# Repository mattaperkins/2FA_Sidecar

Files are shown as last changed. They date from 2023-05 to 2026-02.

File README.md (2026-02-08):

<PRE>
// 2FA Sidecar
// Matt Perkins - Copyright (C) 2025
// Spawned out of the need to often type a lot of two factor authentication
// but still have some security while remaining mostly isolated from the host system.
// See github for 3D models and wiring diagram.
/*

    This program is free software: you can redistribute it and/or modify
    it under the terms of the GNU General Public License as published by
    the Free Software Foundation, either version 3 of the License, or
    (at your option) any later version.

    This program is distributed in the hope that it will be useful,
    but WITHOUT ANY WARRANTY; without even the implied warranty of
    MERCHANTABILITY or FITNESS FOR A PARTICULAR PURPOSE.  See the
    GNU General Public License for more details.

    You should have received a copy of the GNU General Public License
    along with this program.  If not, see <https://www.gnu.org/licenses/>.

*/

</PRE>
<h2>About</h2> 
<p>The 2FA Sidecar is a small external keyboard-like device with five or two keys specifically designed for generating and sending time-based two-factor authentication (2FA) codes with a single key press. It is primarily designed to be compatible with Google's 2FA implementation known as Time-Based One-Time Password (TOTP), which is specified in RFC 6238.
</p><p>
The purpose of the 2FA Sidecar is to simplify the process of using 2FA codes when switching between different security levels in various parts of a network. Instead of having to manually open your phone, retrieve the code, and type it in, the sidecar device allows you to generate and send the code with just a single key press.
</p><p>

The device supports up to five different TOTP codes for different systems, allowing you to manage multiple 2FA-enabled accounts or services. Additionally, it features a TFT screen on the front where you can read the generated code if you prefer to type it manually.
</p><p>

The 2FA Sidecar is compatible with any platform that supports USB HID (Human Interface Device) protocols, making it versatile and usable across a wide range of devices and operating systems.

</p>
<h2>Versions</h2>
<pre>
1.0 Start of project. 
1.3 First Public Release.
1.5 Good working copy with basic cleanup.
1.10 Includes new PIN for access after bootup.
1.11 Added the mini 2 key version with slight change to the code to select at compile time. 
1.13 Make some changes to clean thing up and allow manual entry of time via serial in the future
1.21 Add support for setting the esp32 clock via USB and the host computer clock 
</pre>

<p>
The system is made up of a 5 Key or 3 Key sidecar 3d model that will house an Adafruit Feather S3 Reverse module and 5 Cherry MX type keys It's a fairly simple project to print and build and you should be able to finish it off in a few hours. (including the printing) 
<p>

<a href = "https://www.youtube.com/embed/u4l2TvUD5HY"> 
A short youtube video is also available here. 
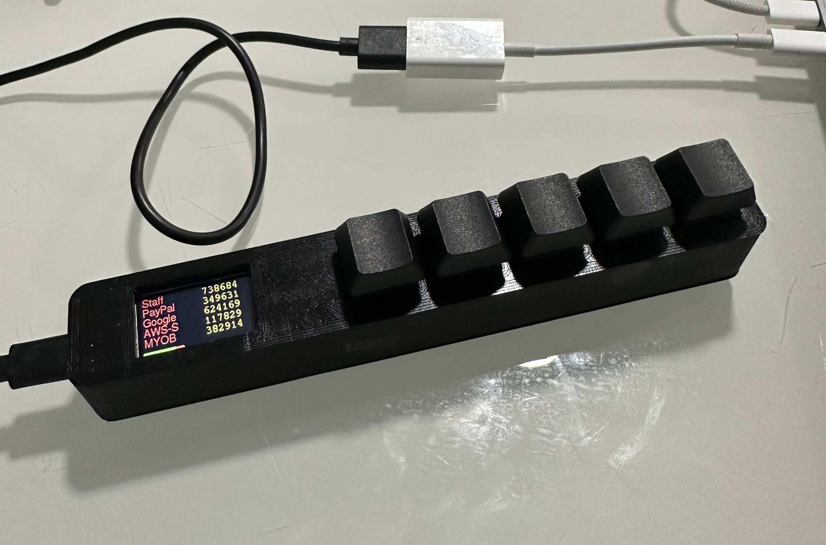
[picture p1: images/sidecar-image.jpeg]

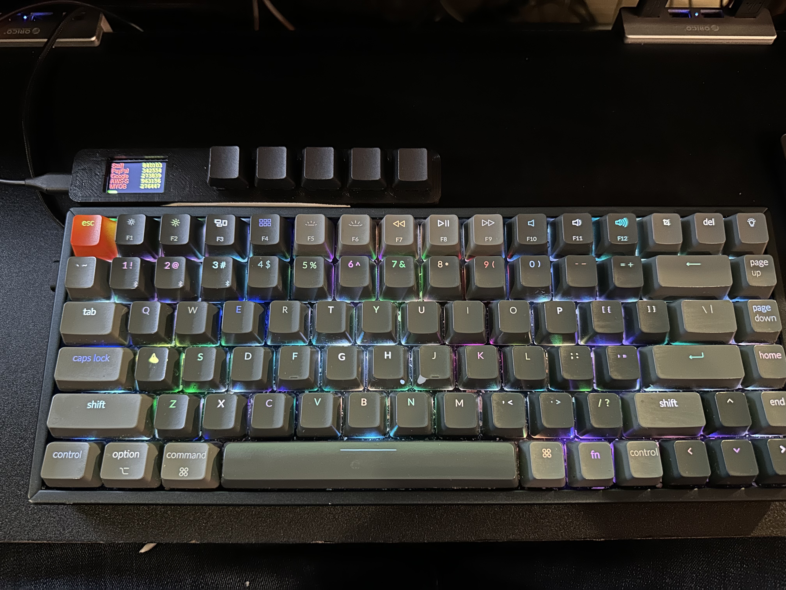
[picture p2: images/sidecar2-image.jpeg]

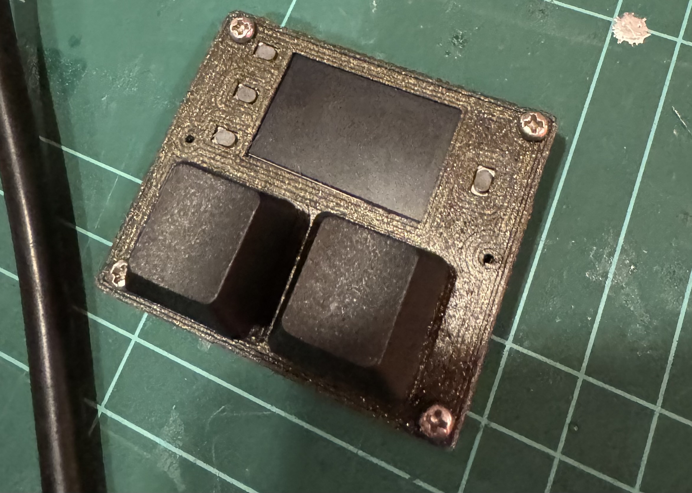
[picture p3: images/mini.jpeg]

</a>
</p>

<h2>Security</h2>

When the sidecar is running in normal mode it is not accessible by any network services and maintains a network connection to update accurate time from a time server only. So it should not be easy for a malicious actor to connect to the sidecar and access the TOTP salt. It would be however possible to download new code to the ESP32 and then retrieve the salts from the parameters memory. So if you want to keep it as secure as possible. You may burn the protective Efuses on the ESP32 to protect flash memory. Even with this done it may be possible to retrieve the salts by much smarter people then i. So i warrant nothing. Use it at your own risk. It goes without question to say also that if someone is in possession of the device they can use your TOTP so you need to keep the device secure. In the same way you would with any key fob. 

<h2>Hardware Required</h2>
<p>Adafruit ESP32-S3 Reverse TFT Feather - 4MB Flash, 2MB PSRAM, STEMMA QT https://www.adafruit.com/product/5691 </p>
<p>Case can be printed from PLA/ABS or whatever really</p>
<p>5 X Cherry MX switches https://core-electronics.com.au/cherry-mx-switch.html click=good</p>
<p>5 X Cherry MX key caps you can source your own or print them many people sell them There's all sorts.</p>
<p>Hookup wire soldering iron and hand tools, super glue </p> <p>- Core electronics stock all of the above</p> 

<h2>Dependences</h2>
<pre>
TOTP-RFC6238-generator - By dirkx - which saved me a lot of work. 
Adafruit_GFX_Library at version 1.11.5 
Adafruit_BusIO at version 1.14.1 
Wire at version 2.0.0
SPI at version 2.0.0
Adafruit_ST7735_and_ST7789_Library at version 1.10.0
Preferences at version 2.0.0
MultiButton at version 1.2.0
USB at version 2.0.0 
WiFi at version 2.0.0
AsyncTCP at version 3.4.10
ESPAsyncWebSrv at version 1.2.9
FS at version 2.0.0
TOTP-RC6236-generator at version 1.0.0
Base32-Decode at version 1.0.1
ESPmDNS at version 2.0.0
ArduinoOTA at version 2.0.0
</pre>

<h2>3D Printing</h2>
The 3d model is based on cherry mx macro pad by LeoAnth found on thingiverse. I remixed that design to fit the Reverse TFT Feather it also has a pin hole so you can access the reset button externally so once complete the boot loader can be accessed.  It prints fine without supports on my snap maker in both ABS and PLA. Print it upside down with no special options. The Lid can then be glued in place once the project is complete and tested. There are also two small plastic squares that can be used to hold the feather in position. Use a drop of glue to hold them in position. I then just used 6 drops of super glue to afix the bottom. 
</p>
<pre>
base.stl - Bottom plate. 
main_body.stl - Main unit print upside down keys pop in. 
shroud.stl - Optional but to put around keys. 
standoffs.stl - Plastic bits to hold the ESP32 in place 
mini.stl - Mini two key version complete. 
</pre>

<h2>Hookup </h3>
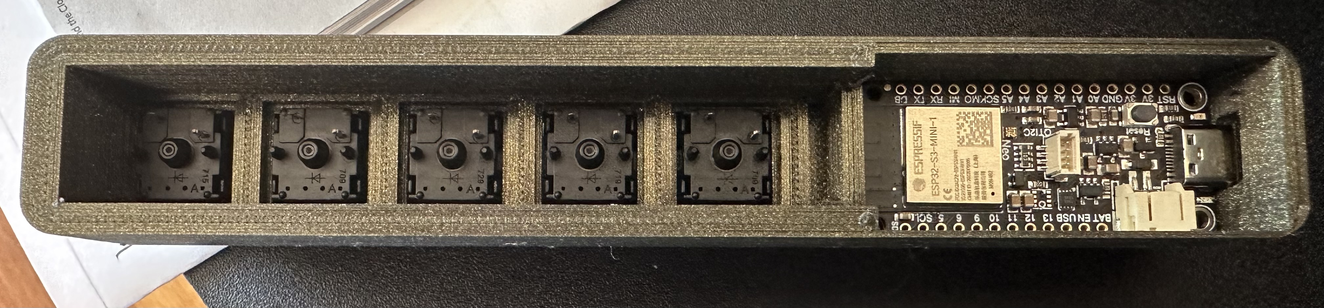
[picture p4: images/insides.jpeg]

To Wire the Cherry MX keys is very simple. Wire one leg of each key to ground and then run a wire from the other leg of each key to the following pins. You might want to solder the switches before you pop them into the case. They can be held with a drop of glue but will fit snugly without as well.
<pre>
Key 1 = Pin (5)
Key 2 = Pin (6)
Key 3 = Pin (9)
Key 4 = Pin (10)
Ket 5 = Pin (11)
</pre>

The two key version you will only need to wire two pins. I found it easer to get the ground from the case of the esp32 RF can. Use some cutters to trim out some space for the wire but not to much as the display is not held firmly in place. 

That's it. Once you flash the esp32 and power up press key 1 within the first 3 second of booting and you will enter a self test and config mode. In the self test mode you can push each key one by one and it will verify your soldering and operation of the keys. Once all 5 keys have been pushed the system will proceed to the config web menu.
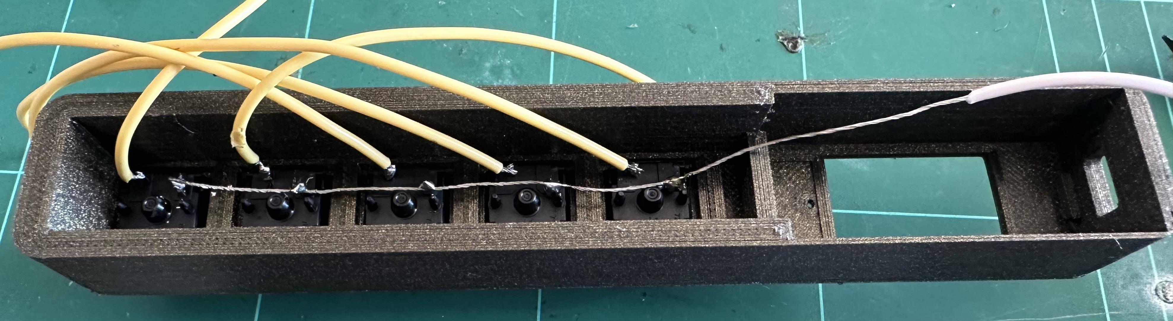
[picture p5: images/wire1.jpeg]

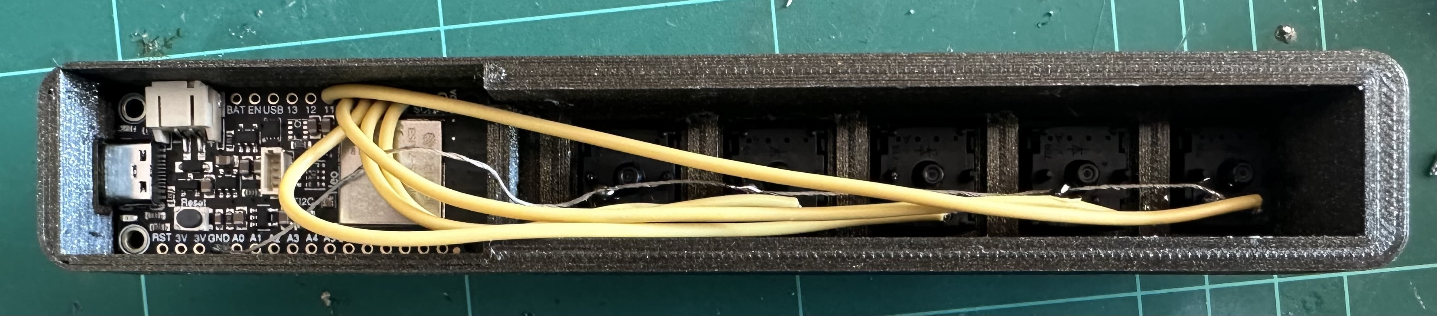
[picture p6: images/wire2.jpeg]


<h2>How to configure</h2>

Configuration is very simple. On powering up the sidecar press key 1 (the key closest to the TFT) within 3 seconds. As it's printing all the dots ... <p> You will then enter the self test menu. Press each key in turn until you see "test pass" If you do not see a test passed check your wiring. Once the test is passed the system will enter a mode where you edit the config</p><p>

At this point you will need to add some TOTP salts. These can be found when your one time password is initially generated on the service you want to authenticate . It will usually represent as a QR code. When you see the QR code there is usually an option display your code manually. Find that option which will typically display a group of base32 letters. It might look something like this WWKAAJJWJJAASZ====. </p><p>  

The sidecar can store up to five TOTP salts (one for each key) so make sure you have them all in advance ready to configure your sidecar. Once your ready and the self test has passed you will be able to connect to the sidecar over wifi. Use your smart phone or computer to scan for the SSID  "Key-Sidecar" and connect. Once connected open your favorite browser and connect to http://192.168.4.1 and you should see the config menu 
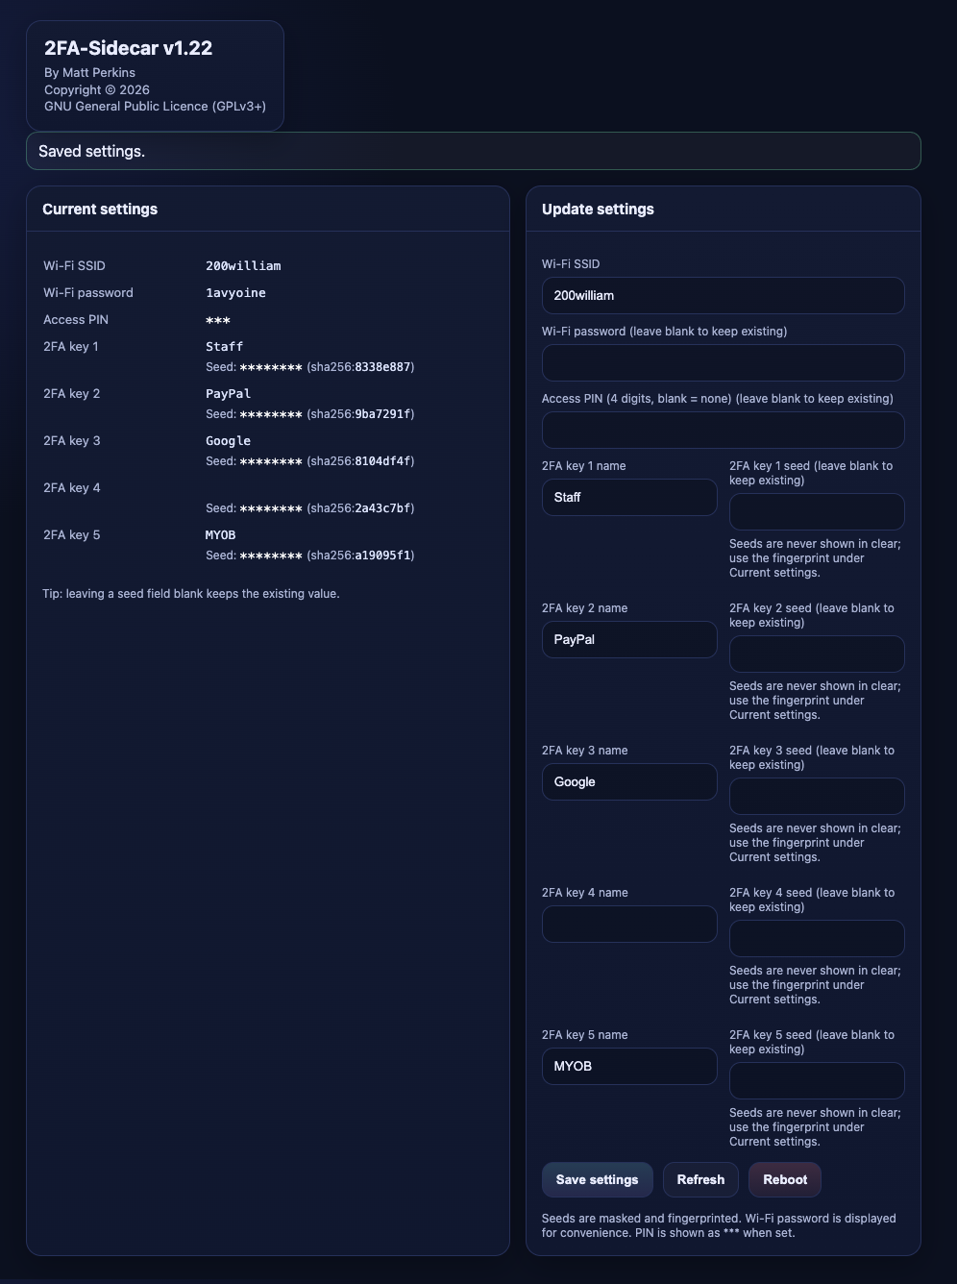
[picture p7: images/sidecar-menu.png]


</p><p> 

You may then configure your system SSID and password so the sidecar can get an accurate time at startup as well as your 5 TOTP's and a corresponding name for each.  
</p><p> 
A note about stored values.  The system does not display a value you have stored after you submit. This is on propose to protect the values stored in those options. If the values were displayed it would be trivial for a bad actor to grab the TOTP salts out of the config menu. </p><p>
<P>
As of version 1.20, there is now an option to set the ESP32 clock via USB for situations where Wi-Fi is not available (such as when you're on the road). If Wi-Fi cannot be found, the TFTP display will show: "WiFi not found. USB fallback." While this message is displayed, use the companion Python program settime.py to set the clock over USB. You will need to edit the Python script to include the correct path to your serial device connected to the sidecar.
</p>

Once everything is configured you can reboot your sidecar and it will boot up in display mode and connect to your local wifi. Grab the time and start spitting out 5 TOTP's every 30 seconds. The unit will also then show up on your computer as a standard USB type keyboard.  When you need to provide a 2FA for authentication on a web site or in a ssh simply tap the key that corresponds to one of the 5 TOTP's you want and the sidecar will type the TOTP for you and press enter. 
</p><p> 
That's it your done. Your 15 second process is now less then 500ms.  Your welcome. 
</p>

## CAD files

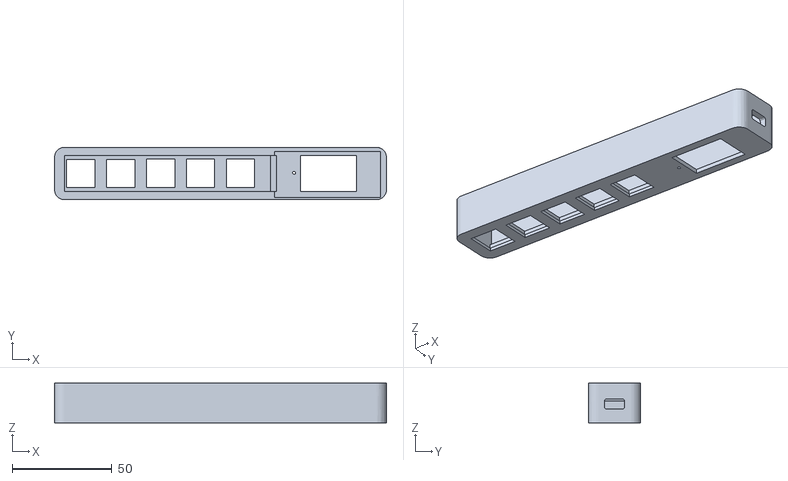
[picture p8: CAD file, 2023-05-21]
3d_model/main_body.stl
166.2 x 26.2 x 20.0

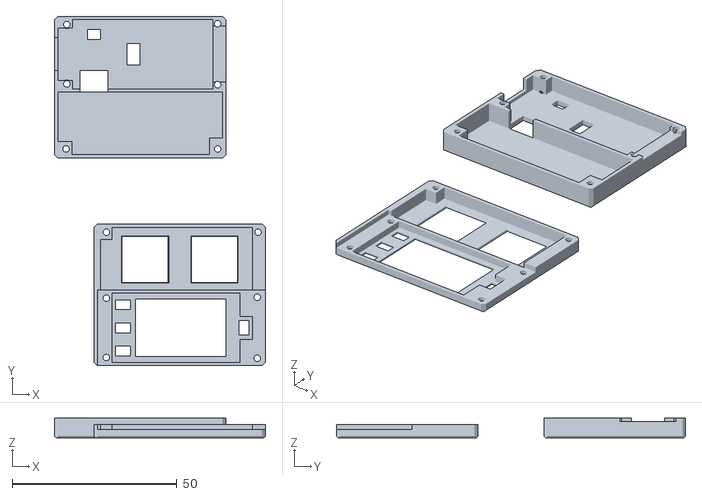
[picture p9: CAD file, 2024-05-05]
3d_model/mini.stl
64.0 x 106.0 x 6.00

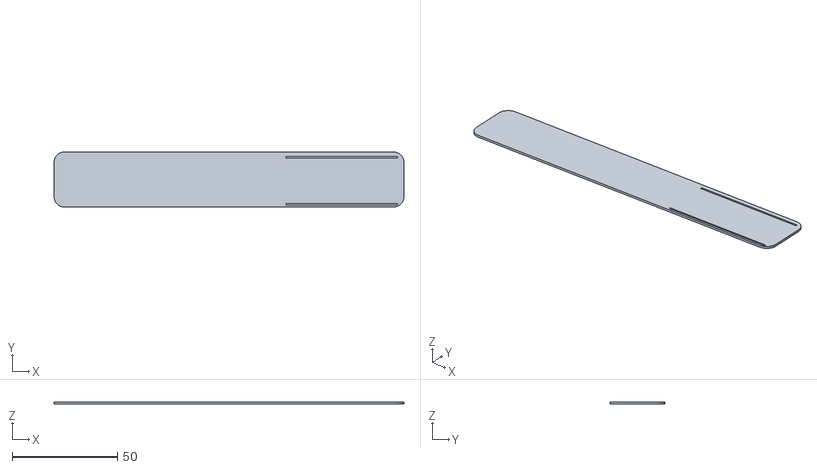
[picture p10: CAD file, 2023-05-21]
3d_model/base.stl
166.2 x 26.2 x 0.998

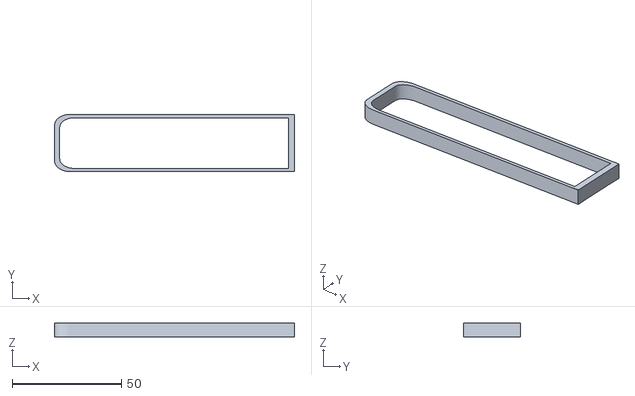
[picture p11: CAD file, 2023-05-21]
3d_model/shround.stl
110.0 x 26.2 x 6.56

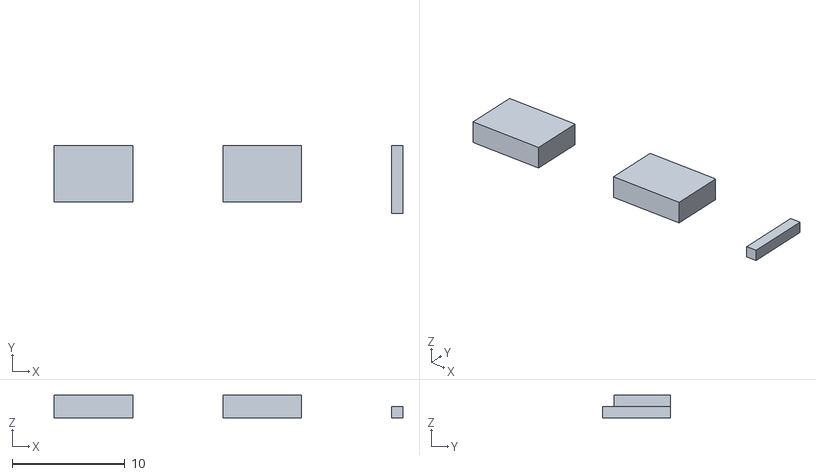
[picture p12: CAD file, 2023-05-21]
3d_model/standoffs.stl
31.0 x 6.00 x 2.00

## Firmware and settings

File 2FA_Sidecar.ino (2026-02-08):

// 2FA Sidecar
// Matt Perkins - Copyright (C) 2025
// Spawned out of the need to often type a lot of two factor authentication
// but still have some security while remaning mostly isolated from the host system.
// See github for 3D models and wiring diagram.
/*

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
*/

// Change for your country.
#define NTP_SERVER "au.pool.ntp.org" //Adjust to your local time perhaps. 
#define TZ "AEST" // Australian Estern time may be needed for clock display in the future. 



// Only other thing to select bellow is if your making the 5 key or 2 key version
// Default is 5 key.


char *mainver = "1.30";

#include <Adafruit_GFX.h>    // Core graphics library
#include <Adafruit_ST7789.h> // Hardware-specific library for ST7789
#include <SPI.h>
#include <Preferences.h> // perstant storage
#include <esp_system.h> 

// Misc Fonts
#include "Fonts/FreeSans9pt7b.h"
#include "Fonts/FreeSans12pt7b.h"
#include "Fonts/FreeSans18pt7b.h"
#include "Fonts/FreeMono12pt7b.h"

#include <string>



#include <PinButton.h> // Button Library 

#include <USB.h>
#include <USBHIDKeyboard.h>

#include <Arduino.h>
#ifdef ESP32
#include <WiFi.h>
#include <AsyncTCP.h>
#elif defined(ESP8266)
#include <ESP8266WiFi.h>
#include <ESPAsyncTCP.h>
#endif
#include <ESPAsyncWebSrv.h>


#include <lwip/apps/sntp.h>
#include <TOTP-RC6236-generator.hpp>
#include <ESPmDNS.h>
#include <ArduinoOTA.h>



// Init HID so we look like a keyboard
USBHIDKeyboard Keyboard;

// Init our 5 keys
int bargraph_pos;
int updateotp;
long time_x;
String inputBuffer = "";
int notime;

PinButton key1(5);
PinButton key2(6);
PinButton key3(9);
PinButton key4(10);
PinButton key5(11);


int keytest = 0;

// Select either the 5 key or 2 key version
// maxkeys = 15 for 5 key
// maxkeys = 3 for 2 key

int maxkeys = 3;
int sline = 0;
int pinno = 0;
int wifitry = 10; // Number of times to try wifi before falling back to serial.
String  in_pin;

// Incorrect Pin Delay
int pindelay = 3000;

AsyncWebServer server(80);

// Setup SSID
String ssid     = "Key-Sidecar";
String password;
String  pin;

String tfa_name_1;
String tfa_seed_1;

String tfa_name_2;
String tfa_seed_2;

String tfa_name_3;
String tfa_seed_3;

String tfa_name_4;
String tfa_seed_4;

String tfa_name_5;
String tfa_seed_5;

// Paramaters wifi
const char* PARAM_INPUT_1 = "ssid";
const char* PARAM_INPUT_2 = "password";
const char* PARAM_INPUT_3 = "pin";

// Paramaters 2FA
const char* TFA_INPUT_1 = "tfa_name_1";
const char* TFA_INPUT_2 = "tfa_seed_1";

const char* TFA_INPUT_3 = "tfa_name_2";
const char* TFA_INPUT_4 = "tfa_seed_2";

const char* TFA_INPUT_5 = "tfa_name_3";
const char* TFA_INPUT_6 = "tfa_seed_3";

const char* TFA_INPUT_7 = "tfa_name_4";
const char* TFA_INPUT_8 = "tfa_seed_4";

const char* TFA_INPUT_9 = "tfa_name_5";
const char* TFA_INPUT_10 = "tfa_seed_5";




// Init Screen
Adafruit_ST7789 tft = Adafruit_ST7789(TFT_CS, TFT_DC, TFT_RST);

// Init Preferences
Preferences preferences;


void setup() {

  
  // turn on backlite
  pinMode(TFT_BACKLITE, OUTPUT);
  digitalWrite(TFT_BACKLITE, HIGH);

  // turn on the TFT / I2C power supply
  pinMode(TFT_I2C_POWER, OUTPUT);
  digitalWrite(TFT_I2C_POWER, HIGH);
  delay(10);

  // initialize TFT
  tft.init(135, 240); // Init ST7789 240x135
  tft.setRotation(3);
  tft.fillScreen(ST77XX_BLACK);
  tft.setFont(&FreeSans9pt7b);

  // Print Bootup
  tft.setCursor(0, 0);
  tft.setTextColor(ST77XX_WHITE);
  tft.setTextWrap(true);
  tft.printf("\n2FA-Sidecar Ver %s\nBy Matt Perkins (C) 2024\n", mainver);
  tft.printf("Reset reason: %d\n", esp_reset_reason());
  tft.printf("Press K1 to enter config/test\n");

  // Check for key and go to setup /test mode
  int lcount = 0 ;
  while (lcount < 140) {

    key1.update();

    if (key1.isClick()) {
      setup_test();
      ESP.restart();
    }

    tft.printf(".");
    delay(10);
    lcount++;
  }

  tft.setFont(&FreeSans9pt7b);
  tft.fillScreen(ST77XX_BLACK);
  tft.setTextColor(ST77XX_WHITE);
  tft.setCursor(1, 15);
  tft.printf("2FA-Sidecar V%s - startup\n", mainver);

  preferences.begin("2FA_Sidecar", false);

  ssid = preferences.getString("ssid", "");
  password = preferences.getString("password", "");


  // load all pramaters
  tfa_name_1 = preferences.getString("tfa_name_1", "");
  tfa_seed_1 = preferences.getString("tfa_seed_1", "");

  tfa_name_2 = preferences.getString("tfa_name_2", "");
  tfa_seed_2 = preferences.getString("tfa_seed_2", "");

  tfa_name_3 = preferences.getString("tfa_name_3", "");
  tfa_seed_3 = preferences.getString("tfa_seed_3", "");

  tfa_name_4 = preferences.getString("tfa_name_4", "");
  tfa_seed_4 = preferences.getString("tfa_seed_4", "");

  tfa_name_5 = preferences.getString("tfa_name_5", "");
  tfa_seed_5 = preferences.getString("tfa_seed_5", "");

  WiFi.begin(ssid, password);

  sline = 0;
  while (WiFi.status() != WL_CONNECTED) {
    delay(1000);
    tft.printf("Establishing WiFi %d\n", wifitry);
    sline = sline + 1;
    wifitry = wifitry - 1;
    if (sline > 4) {
      tft.fillScreen(ST77XX_BLACK);
      tft.setTextColor(ST77XX_WHITE);
      tft.setCursor(1, 15);
      sline = 0 ;
    }
    if (wifitry == 0) {
      break;
    }
  }

  // If Wifi is found get time that way else try the serial port.
  if (wifitry != 0) {
    tft.fillScreen(ST77XX_BLACK);
    tft.setTextColor(ST77XX_WHITE);
    tft.setCursor(1, 15);
    tft.print("IP: ");
    tft.println(WiFi.localIP());
    tft.print("Wifi: ");
    tft.print(WiFi.RSSI());
    // start the NTP client
    configTzTime(TZ, NTP_SERVER);
    tft.println();
    tft.printf("NTP started:%s", TZ);
    time_t t = time(NULL);
    tft.printf(":%d", t);
    tft.println();
    delay(1000);
  } else {
    // Wifi Not found get time via serial/usb
    notime = 0;
    tft.fillScreen(ST77XX_BLACK);
    tft.setTextColor(ST77XX_WHITE);
    tft.setCursor(1, 15);
    tft.print("WiFi not found. USB fallback");

    Serial.begin(115200);
    Serial.println("Enter a Unix timestamp:");
    while (notime == 0) {
      while (Serial.available()) {
        char c = Serial.read();

        if (c == '\n' || c == '\r') {
          if (inputBuffer.length() > 0) {
            time_t unixTime = inputBuffer.toInt();

            struct timeval tv = { unixTime, 0 };  // seconds, microseconds
            settimeofday(&tv, nullptr);          // Set system time

            struct tm timeinfo;
            if (getLocalTime(&timeinfo)) {
              Serial.print("Time set to: ");
              Serial.println(&timeinfo, "%A, %B %d %Y %H:%M:%S");
              notime = 1;
            } else {
              Serial.println("Failed to get local time");
            }

            inputBuffer = "";  
            Serial.println("OK");
          }
        } else if (isDigit(c)) {
          inputBuffer += c;
        }
      }
      delay(10);
    }

  }


  // Check to seee if we have PIN set and ask if we do.
  pin = preferences.getString("pin", "");
  const char* npin = pin.c_str();
  if (strlen(npin) > 3) {
    tft.setCursor(25, 25);
    tft.setFont(&FreeSans12pt7b);
    tft.fillScreen(ST77XX_BLACK);
    tft.setTextColor(ST77XX_YELLOW);
    tft.print("PIN?");
    // read keys for PIN

    while (1) {
      static unsigned long lst = millis();
      if (millis() - lst < 1000) {
        // UPDATE KEYS
        key1.update();
        key2.update();
        key3.update();
        key4.update();
        key5.update();
      }

      lst = millis();

      if (key1.isClick()) {
        pinno = pinno + 1;
        in_pin = in_pin + "1";
        tft.print("*");
      }

      if (key2.isClick()) {
        pinno = pinno + 1;
        in_pin = in_pin + "2";
        tft.print("*");
      }

      if (key3.isClick()) {
        pinno = pinno + 1;
        in_pin = in_pin + "3";
        tft.print("*");
      }

      if (key4.isClick()) {
        pinno = pinno + 1;
        in_pin = in_pin + "4";
        tft.print("*");
      }

      if (key5.isClick()) {
        pinno = pinno + 1;
        in_pin = in_pin + "5";
        tft.print("*");
      }

      if ( pinno == 4) {
        if (in_pin == npin) {
          tft.println();
          tft.println("Correct.");
          break;
        } else {
          tft.println();
          tft.print("Incorrect!");
          delay(pindelay);
          ESP.restart();
        }
      }
    }



  } // end check PIN


  tft.setTextColor(ST77XX_WHITE);


  // Iniz Keyboard and begin display.
  tft.setFont(&FreeSans9pt7b);

  tft.println("Iniz USB keybaord\n");
  Keyboard.begin();
  USB.begin();
  delay(2000);
  tft.fillScreen(ST77XX_BLACK);
  tft.setTextColor(ST77XX_WHITE);
  updateotp = 1;



}

void loop() {
  static unsigned long lst = millis();
  if (millis() - lst < 1000) {
    // UPDATE KEYS
    key1.update();
    key2.update();
    key3.update();
    key4.update();
    key5.update();
  }

  lst = millis();



  // Update Time.

  time_t t = time(NULL);

  if (t < 1000000) {
    delay(500);
    return;
  };


  // Print Bargraph
  bargraph_pos = (t % 60);
  if (bargraph_pos > 29) {
    bargraph_pos = bargraph_pos - 30;
  }

  bargraph_pos = bargraph_pos * 3;
  if (bargraph_pos < 70) {
    tft.fillCircle(bargraph_pos, 125, 3, ST77XX_GREEN);
  } else {
    tft.fillCircle(bargraph_pos, 125, 3, ST77XX_RED);
  }

  if (bargraph_pos == 0) {
    updateotp = 1;
  }


  // Display updated OTP per key

  if (updateotp == 1) {
    updateotp = 0;
    tft.setTextColor(ST77XX_YELLOW);
    tft.setFont(&FreeSans12pt7b);
    tft.fillScreen(ST77XX_BLACK);

    // Key 1
    if (String * otp1 = TOTP::currentOTP(tfa_seed_1)) {
      tft.setCursor(3, 17);
      tft.setTextColor(ST77XX_RED);
      tft.setFont(&FreeSans12pt7b);
      tft.print(tfa_name_1);
      tft.setCursor(140, 17);
      tft.setTextColor(ST77XX_YELLOW);
      tft.setFont(&FreeMono12pt7b);
      tft.println(*otp1);
    } else {
      tft.setCursor(3, 17);
      tft.setTextColor(ST77XX_RED);
      tft.print("NO VALID CONFIG");
      delay(10000);
      ESP.restart();

    };

    // Key 2
    if (String * otp2 = TOTP::currentOTP(tfa_seed_2)) {
      tft.setCursor(3, 40);
      tft.setTextColor(ST77XX_RED);
      tft.setFont(&FreeSans12pt7b);
      tft.print(tfa_name_2);
      tft.setCursor(140, 40);
      tft.setTextColor(ST77XX_YELLOW);
      tft.setFont(&FreeMono12pt7b);
      tft.println(*otp2);
    };

    // Key 3
    if (String * otp3 = TOTP::currentOTP(tfa_seed_3)) {
      tft.setCursor(3, 63);
      tft.setTextColor(ST77XX_RED);
      tft.setFont(&FreeSans12pt7b);
      tft.print(tfa_name_3);
      tft.setCursor(140, 63);
      tft.setTextColor(ST77XX_YELLOW);
      tft.setFont(&FreeMono12pt7b);
      tft.println(*otp3);
    };

    // Key 4
    if (String * otp4 = TOTP::currentOTP(tfa_seed_4)) {
      tft.setCursor(3, 86);
      tft.setTextColor(ST77XX_RED);
      tft.setFont(&FreeSans12pt7b);
      tft.print(tfa_name_4);
      tft.setCursor(140, 86);
      tft.setTextColor(ST77XX_YELLOW);
      tft.setFont(&FreeMono12pt7b);
      tft.println(*otp4);
    };

    // Key 5
    if (String * otp5 = TOTP::currentOTP(tfa_seed_5)) {
      tft.setCursor(3, 109);
      tft.setTextColor(ST77XX_RED);
      tft.setFont(&FreeSans12pt7b);
      tft.print(tfa_name_5);
      tft.setCursor(140, 109);
      tft.setTextColor(ST77XX_YELLOW);
      tft.setFont(&FreeMono12pt7b);
      tft.println(*otp5);
    };

    // Make up the rest of the second so we dont fliker the screen.
    delay(999);

  }


  // check keypress
  if (key1.isClick()) {
    String * otp1 = TOTP::currentOTP(tfa_seed_1);
    pinMode(LED_BUILTIN, OUTPUT);
    digitalWrite(LED_BUILTIN, HIGH);
    Keyboard.println(*otp1);
    digitalWrite(LED_BUILTIN, LOW);
  }

  if (key2.isClick()) {
    String * otp2 = TOTP::currentOTP(tfa_seed_2);
    pinMode(LED_BUILTIN, OUTPUT);
    digitalWrite(LED_BUILTIN, HIGH);
    Keyboard.println(*otp2);
    digitalWrite(LED_BUILTIN, LOW);
  }

  if (key3.isClick()) {
    String * otp3 = TOTP::currentOTP(tfa_seed_3);
    pinMode(LED_BUILTIN, OUTPUT);
    digitalWrite(LED_BUILTIN, HIGH);
    Keyboard.println(*otp3);
    digitalWrite(LED_BUILTIN, LOW);
  }

  if (key4.isClick()) {
    String * otp4 = TOTP::currentOTP(tfa_seed_4);
    pinMode(LED_BUILTIN, OUTPUT);
    digitalWrite(LED_BUILTIN, HIGH);
    Keyboard.println(*otp4);
    digitalWrite(LED_BUILTIN, LOW);
  }

  if (key5.isClick()) {
    String * otp5 = TOTP::currentOTP(tfa_seed_5);
    pinMode(LED_BUILTIN, OUTPUT);
    digitalWrite(LED_BUILTIN, HIGH);
    Keyboard.println(*otp5);
    digitalWrite(LED_BUILTIN, LOW);
  }
  // Hold down k5 to restart.
  if (key5.isLongClick()) {
    ESP.restart();
  }



}

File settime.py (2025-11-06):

#!/usr/local/bin/python
# Script to set the time via USB fallback if Wi-Fi is not available.
# Compatible with macOS and Linux using /dev/tty.usbmodem*
# Works with Python 2.7+ and Python 3.x

import time
import serial
import glob
import sys

BAUD_RATE = 115200

def list_serial_ports():
    # List all devices that match USB modem pattern
    return glob.glob('/dev/tty.usbmodem*')

def choose_serial_port(ports):
    if not ports:
        print("No USB serial devices found.")
        return None

    if len(ports) == 1:
        print("Found one serial port: {}".format(ports[0]))
        return ports[0]

    print("Available USB serial devices:")
    for i, port in enumerate(ports, 1):
        print("{}: {}".format(i, port))

    while True:
        try:
            # raw_input for Python 2, input for Python 3
            if sys.version_info[0] < 3:
                choice = int(raw_input("Select the serial device by number: "))
            else:
                choice = int(input("Select the serial device by number: "))
            if 1 <= choice <= len(ports):
                return ports[choice - 1]
            else:
                print("Invalid choice. Please enter a number between 1 and {}.".format(len(ports)))
        except ValueError:
            print("Invalid input. Please enter a number.")

def main():
    ports = list_serial_ports()
    serial_port = choose_serial_port(ports)

    if not serial_port:
        return

    print("Using serial port: {}".format(serial_port))

    try:
        ser = serial.Serial(serial_port, BAUD_RATE, timeout=2)
        time.sleep(2)  # Give the microcontroller time to reset

        timestamp = int(time.time())
        print("Sending current Unix time: {}".format(timestamp))

        ser.write((str(timestamp) + '\n').encode())

        time.sleep(1)
        while ser.inWaiting():
            line = ser.readline().strip()
            print(line.decode())

        ser.close()

    except serial.SerialException as e:
        print("Serial error: {}".format(e))

if __name__ == "__main__":
    main()

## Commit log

2023-05-21 Add STL models
    [base.stl, main_body.stl, shround.stl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]
2023-05-30 fixed time zone and test new totp from param
    [2FA_Sidecar.ino]
2023-06-02 1.02 fix some error reporting on blank modules
    [2FA_Sidecar.ino]
2023-06-03 moving around
    [base.stl, main_body.stl, shround.stl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]
2023-06-18 some new images and hold down k5 to reboot feature
    [2FA_Sidecar.ino]
2023-06-20 Ver 1.10 include PIN for access
2024-05-05 Added minit 12 key version
    [mini.stl]
2025-06-01 added menu to python script to allow for choosing a device
2026-02-08 Added some slight debuging code and tcp async fixes Fixed readme to reflect new library
    [2FA_Sidecar.ino, setup_menu.ino]
